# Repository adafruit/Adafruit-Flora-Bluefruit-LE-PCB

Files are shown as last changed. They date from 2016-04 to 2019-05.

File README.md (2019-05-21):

## Adafruit Flora Bluefruit LE PCB
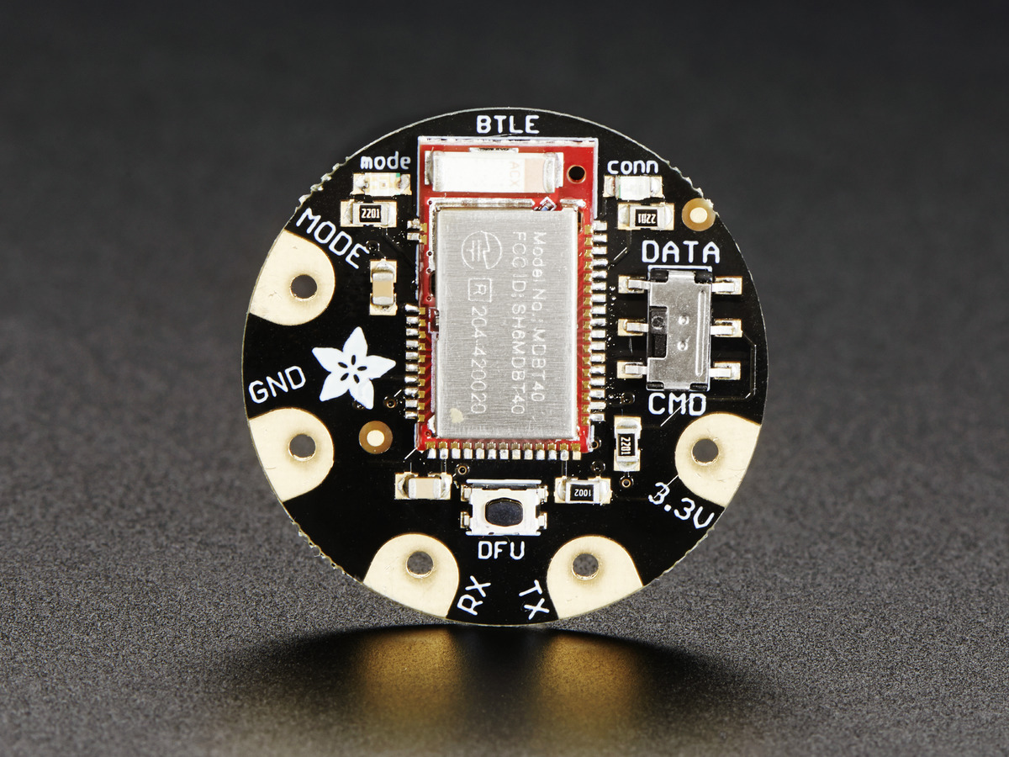
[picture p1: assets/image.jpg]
<a href="http://www.adafruit.com/products/2487"><br/>
Click here to purchase one from the Adafruit shop</a>

Would you like to add powerful and easy-to-use Bluetooth Low Energy to your wearable FLORA project? Heck yeah! With BLE now included in modern smart phones and tablets, its fun to add wireless connectivity. So what you really need is the new Adafruit Flora Bluefruit LE!

The Flora Bluefruit LE makes it easy to add Bluetooth Low Energy connectivity to your Flora. Sew 4 traces (or solder 4 wires) and BooM! Bluetooth Low Energy!

Get started fast with the Bluefruit App!

Using our Bluefruit iOS App or Android App, you can quickly get your interactive project prototyped by using your iOS or Android phone/tablet as a controller. We have a color picker, quaternion/accelerometer/gyro/magnetometer or location (GPS), and an 8-button control game pad. After you connect to the Bluefruit, you can send commands wirelessly in under 10 minutes

PCB files for the Adafruit Bluefruit LE PCB. The format is EagleCAD schematic and board layout
- https://www.adafruit.com/product/2487

### License

Adafruit invests time and resources providing this open source design, please support Adafruit and open-source hardware by purchasing products from [Adafruit](https://www.adafruit.com)!

All text above must be included in any redistribution

Designed by Limor Fried/Ladyada for Adafruit Industries.
Creative Commons Attribution/Share-Alike, all text above must be included in any redistribution. 
See license.txt for additional information.

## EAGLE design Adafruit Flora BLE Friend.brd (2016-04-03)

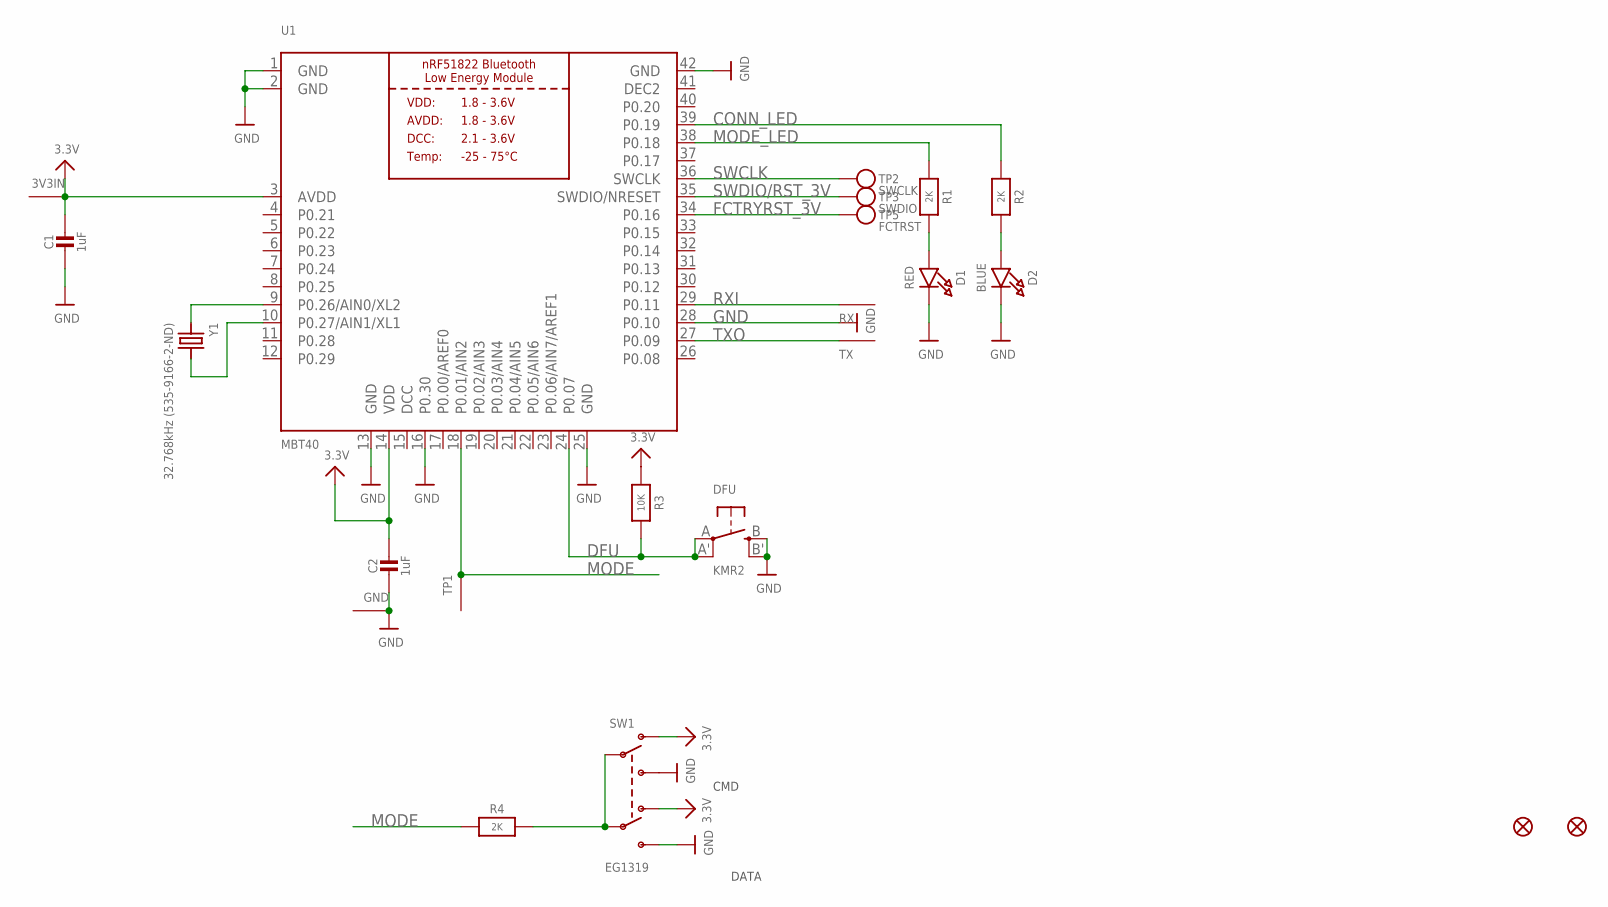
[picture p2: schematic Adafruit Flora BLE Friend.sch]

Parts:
3V3IN: SEWTAP-2.0IN; SEWINGTAP_2.0
C1, C2: 1uF; 0805-NO
D1: RED; CHIPLED_0805_NOOUTLINE
D2: BLUE; CHIPLED_0805_NOOUTLINE
DFU: KMR2; BTN_KMR2_4.6X2.8
FID1, FID2: FIDUCIAL""; FIDUCIAL_1MM
GND: SEWTAP-2.0IN; SEWINGTAP_2.0
R1, R2, R4: 2K; 0805-NO
R3: 10K; 0805-NO
RX: SEWTAP-2.0IN; SEWINGTAP_2.0
SW1: EG1319; EG1390
TP1: SEWTAP-2.0IN; SEWINGTAP_2.0
TP2: SWCLK; PAD-1.5X2.0
TP3: SWDIO; PAD-1.5X2.0
TP5: FCTRST; PAD-1.5X2.0
TX: SEWTAP-2.0IN; SEWINGTAP_2.0
U1: MBT40; BLE_MODULE_RAYTAC_MDBT40
Y1: 32.768kHz (535-9166-2-ND); CRYSTAL_CYL_2X6MM_SMT

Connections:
3.3V: 3V3IN.P$1, C1.1, C2.1, R3.1, SW1.O1, SW1.O2, U1.3 (AVDD), U1.14 (VDD)
CONN_LED: R2.1, U1.39 (P0.19)
DCC: U1.15 (DCC)
DEC2: U1.41 (DEC2)
DFU: DFU.A, DFU.A' (P1), R3.2, U1.24 (P0.07)
FCTRYRST_3V: TP5.P$1, U1.34 (P0.16)
GND: C1.2, C2.2, D1.C, D2.C, DFU.B (S), DFU.B' (S1), GND.P$1, SW1.S1, SW1.S2, U1.1 (GND), U1.2 (GND), U1.13 (GND), U1.16 (P0.30), U1.25 (GND), U1.28 (P0.10), U1.42 (GND)
MODE: R4.1, TP1.P$1, U1.18 (P0.01/AIN2)
MODE_LED: R1.1, U1.38 (P0.18)
unnamed: R4.2, SW1.P1, SW1.P2
unnamed: D1.A, R1.2
unnamed: D2.A, R2.2
unnamed: U1.9 (P0.26/AIN0/XL2), Y1.1
unnamed: U1.10 (P0.27/AIN1/XL1), Y1.2
RXI: RX.P$1, U1.29 (P0.11)
SWCLK: TP2.P$1, U1.36 (SWCLK)
SWDIO/RST_3V: TP3.P$1, U1.35 (SWDIO/NRESET)
TXO: TX.P$1, U1.27 (P0.09)

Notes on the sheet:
DATA
CMD

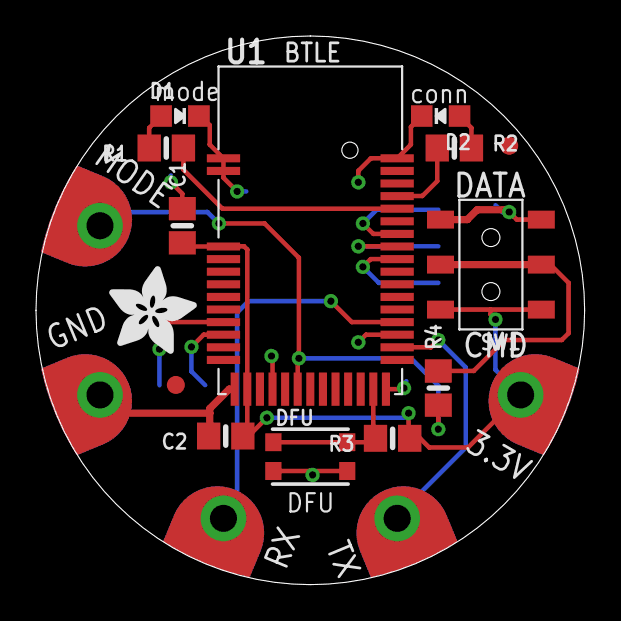
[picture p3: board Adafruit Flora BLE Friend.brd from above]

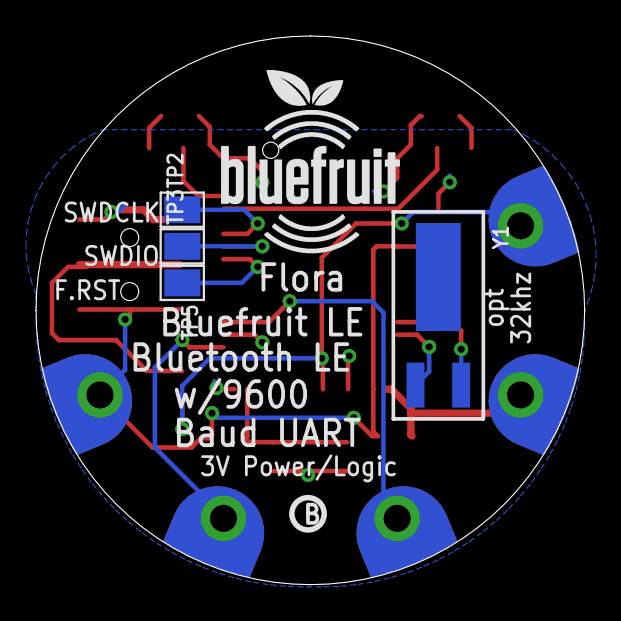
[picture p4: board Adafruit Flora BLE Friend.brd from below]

Board: 2 copper layers, 30.5 x 30.5 mm, 26 parts (7 on the bottom side), 16 nets.

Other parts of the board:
U$6: ADAFRUIT_5MM
U$7: FLORASMALL
U$23: BLUEFRUITLOGO_100MM
U$24: PCBFEAT-REV-040
